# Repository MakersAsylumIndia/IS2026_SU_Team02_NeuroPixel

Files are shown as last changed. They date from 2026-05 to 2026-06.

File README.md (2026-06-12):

# IS2026 Summer - NeuroPixel: EMG-Controlled Accessible Gaming Console and Arcade Hub

**Description:**

NeuroPixel is an accessible EMG-controlled gaming console and arcade hub designed for individuals with physical disabilities and limited mobility. Instead of traditional controllers, the system uses EMG (Electromyography) sensors to detect voluntary muscle signals from areas such as the jaw, neck, shoulders, forehead, or facial muscles. These signals are processed by a microcontroller and converted into gameplay actions like jumping, moving, shooting, or selecting options.

The platform features five classic arcade-style games, including Google Chrome Dino, Flappy Bird, Pac-Man, Snake, and Space Invaders, all adapted for muscle-based interaction. NeuroPixel includes adaptive calibration, customizable sensitivity, audio feedback, and large visual indicators to ensure comfortable and accurate gameplay for users with varying levels of mobility and muscle strength.

Beyond entertainment, NeuroPixel also promotes cognitive engagement, reflex improvement, concentration, and neurological response development through interactive gameplay. Built using affordable and widely available components such as MyoWare EMG sensors and ESP32/Arduino microcontrollers, the system offers a low-cost and inclusive gaming solution. NeuroPixel bridges assistive technology, rehabilitation, and recreation, enabling users with disabilities to independently enjoy digital gaming experiences.

**Description of the contents od each folder:**

**CODE Folder**
Contains all software and programming files required for NeuroPixel. This includes EMG signal processing code, ESP32 firmware, calibration algorithms, game control mapping, Bluetooth/Wi-Fi communication scripts, and accessible game integration files for Chrome Dino, Flappy Bird, Pac-Man, Snake, and Space Invaders. It also includes testing scripts, debugging utilities, and libraries used for EMG signal filtering and command recognition.

**CAD Folder**
Contains all 3D design and mechanical files related to the physical structure of NeuroPixel. This includes enclosure designs, wearable sensor mounts, arcade console casing models, controller housing, mounting brackets, and assembly designs created using CAD software such as FreeCAD or Fusion 360. The folder may also include STL files for 3D printing and technical dimension drawings.

**Electronics Folder**
Contains circuit diagrams, wiring schematics, PCB layouts, component datasheets, and hardware integration details for the NeuroPixel system. This folder includes EMG sensor connections, ESP32/Arduino interfacing diagrams, power management circuits, OLED/display connections, battery systems, and calibration hardware documentation.

**Documentation Folder**
Contains project reports, research material, setup guides, user manuals, calibration instructions, accessibility documentation, testing reports, and presentation files explaining the working and objectives of NeuroPixel.

**Assets Folder**
Contains images, logos, UI graphics, sound effects, game icons, accessibility visuals, demo screenshots, and promotional material used in the NeuroPixel interface and presentations.

## License

Licenses

<a href="LICENSE.md">Open Source Licenses Facts</a>

#### Hardware
CERN Open Hardware License Version 2 - Strongly Reciprocal ([CERN-OHL-S-2.0](https://spdx.org/licenses/CERN-OHL-S-2.0.html)).

#### Software
MIT open source [license](http://opensource.org/licenses/MIT).

#### Documentation:
<br />This work is licensed under a <a rel="license" href="http://creativecommons.org/licenses/by/4.0/">Creative Commons Attribution 4.0 International License</a>.

---
## [OSHWA Certification](https://certification.oshwa.org/list.html)

[OSHW] IN000093 | Certified open source hardware | oshwa.org/cert

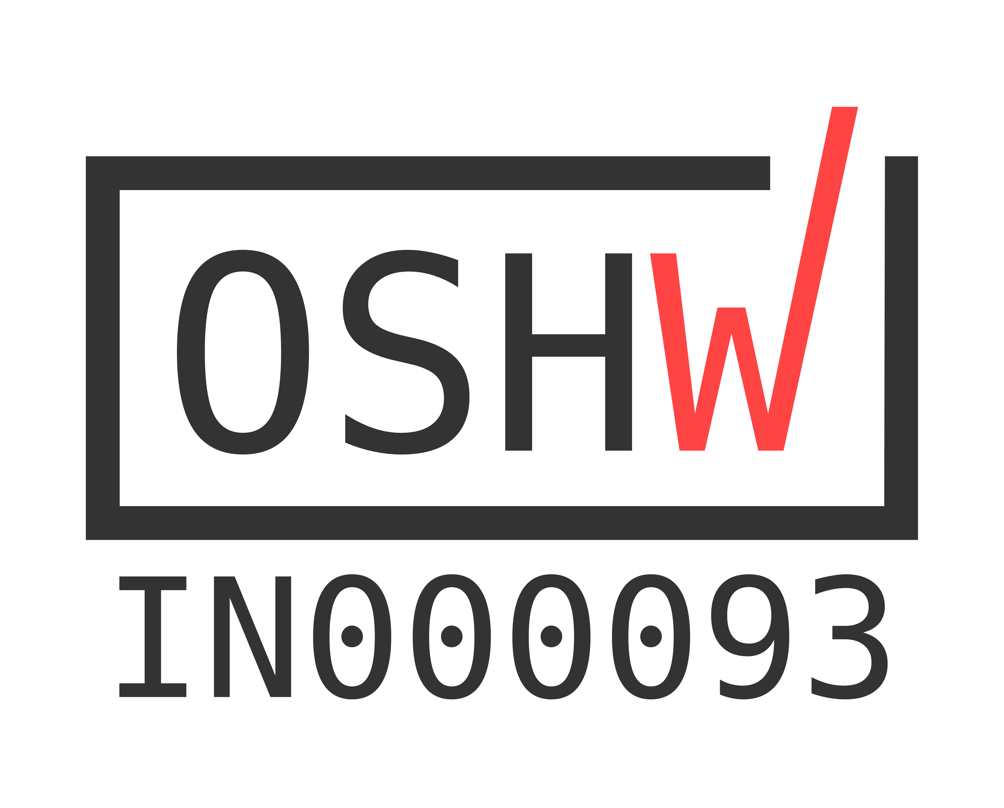
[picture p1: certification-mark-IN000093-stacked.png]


---

## 📬 Contact/Team

[@botadaranemi-arch] (https://github.com/botadaranemi-arch)

[@jatindixit3] (https://github.com/jatindixit3)

[@shreyasidaga] (https://github.com/shreyasidaga)

[@aryamanmehrotra1802-png] (https://github.com/aryamanmehrotra1802-png)

[@atharvkirloskar] (https://github.com/atharvkirloskar)

[Maker's Asylum] (https://github.com/MakersAsylumIndia)

> ---

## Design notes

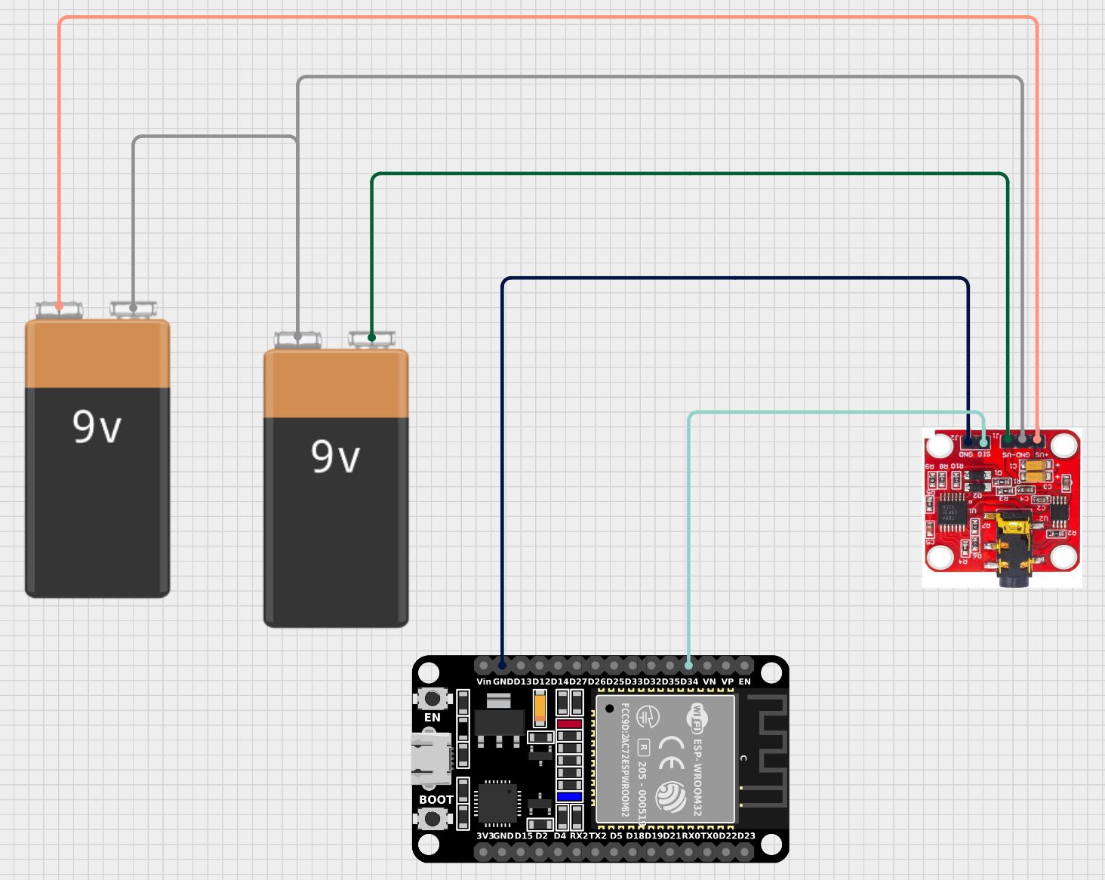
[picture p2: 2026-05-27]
Electronics/emg 1.jpeg

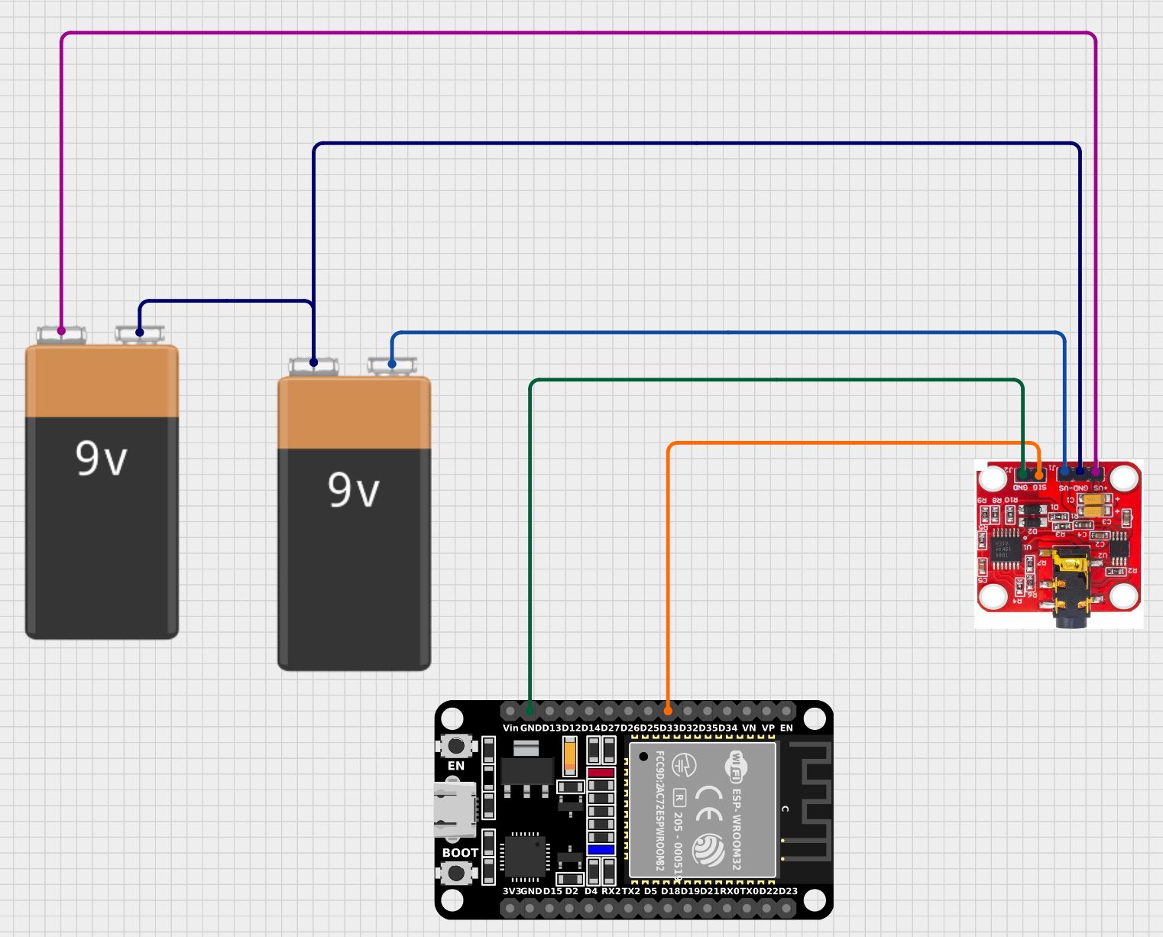
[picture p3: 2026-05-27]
Electronics/emg 4.jpeg

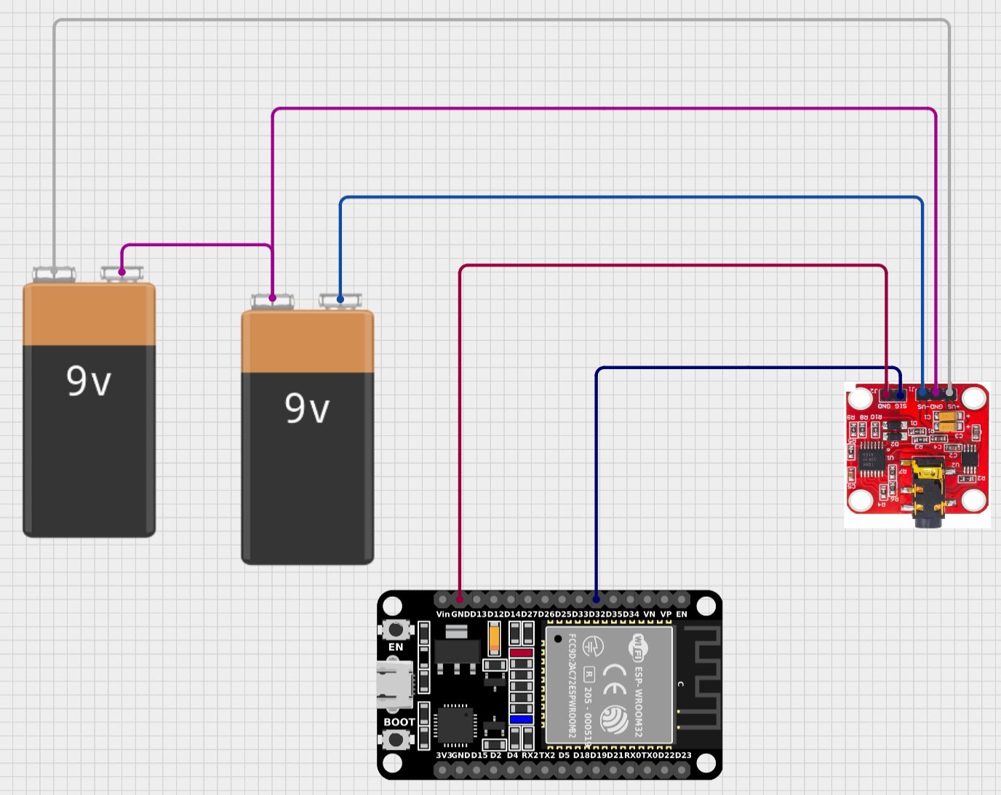
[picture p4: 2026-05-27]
Electronics/emg 3.jpeg

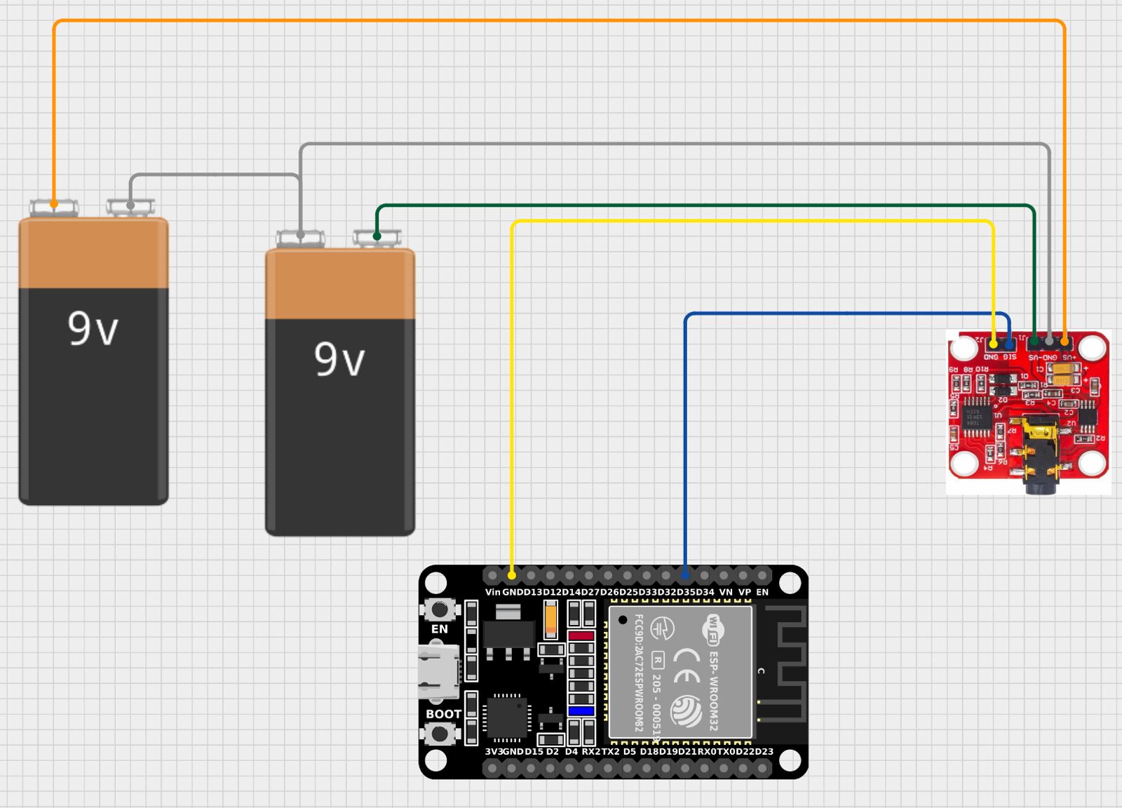
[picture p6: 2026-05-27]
Electronics/emg 2.jpeg

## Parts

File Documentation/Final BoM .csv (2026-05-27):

SR NO | PRODUCT NAME | QTY | TYPE | REFERENCE LINK | ADDITONAL DETAILS
1 | ESP32 Node MCU WiFi Bluetooth Development Module (30 Pin) - CP2102 MICRO | 3 | Electronics | https://www.flyrobo.in/esp32-node-mcu-wifi-bluetooth-development-module-30-pin?description=true | Main controller used to process EMG signals and run the project.
2 | EMG Muscle Sensor V3.0 with Cable and Electrodes | 5 | Electronics | https://robu.in/product/advancer-technologies-emg-muscle-sensor-v3-0-with-cable-and-electrodes/ | Detects electrical activity from muscles and converts it into readable signals.
3 | Bio Amp Muscle Band | 5 | Electronics | https://robu.in/product/muscle-bioamp-band-emg-band | Wearable band used to comfortably capture muscle movement signals from the body.
4 | WLY104050 3.7V 2500mAh 1S LiPo Battery (Wearable IoT) | 1 | Power | https://www.flyrobo.in/hw-battery-9v-for-arduino-rpi-robotics?description=true | Portable rechargeable battery used to power the wearable device.
5 | TP51000 Li-Ion Charging Module with Protection (Type-C) | 1 | Power | https://robu.in/product/tp5100-4-2v-8-4v-single-double-lithium-battery-charge-management-lion-battery-compatible-2a-charging-board | Charges the LiPo battery safely through a Type-C connector with protection features.
6 | Perf board double sided | 4 | Prototyping | https://robu.in/product/9-x-15-cm-universal-pcb-prototype-board-single-sided-2-54mm-hole-pitch?gad_source=1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 | Used to permanently solder and connect electronic components into a compact circuit.
7 | TP4056 1A Li-Ion Charging Board Micro USB with Protection | 1 | Power | https://robu.in/product/tp4056-1a-li-ion-battery-charging-board-micro-usb-with-current-protection-type-c-connector | Safely charges single-cell Li-ion/LiPo batteries using a Micro USB input.
8 | 20CM Dupont Wire Combo (M-M + M-F + F-F, 40pcs each = 120pcs) | 2 | Prototyping | https://robu.in/product/20-cm-40-pin-dupont-male-male-male-female-female-female-cable-combo/ | Used for temporary electrical connections between components during prototyping.
9 | 470 Ohm Resistor 1/4W (pack of 25) | 1 | Electronics | https://www.electropi.in/470-ohm-resistance?gad_source=1&gad_campaignid=23329895947 | Limits current flow to protect components and stabilize circuits.
10 | 75 Ohm Resistor 1/4W (pack of 25) | 1 | Electronics | https://www.electropi.in/75-ohm-resistance?gad_source=1&gad_campaignid=23329895947 | Used for signal conditioning, impedance matching, or current limiting in circuits.
11 | M3 Inserts | 1 | Mechanical | https://www.flyrobo.in/m2.5-x-5mm-brass-heat-set-threaded-round-insert-nut?tracking=ads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 | Provide strong threaded mounting points for screws in enclosures or 3D prints.
12 | Rca Composite Cable | 1 | Electronics | https://www.flyrobo.in/3.5mm-male-plug-3-rca-male-audio-video-cable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 | Transfers analog video or audio signals between devices.
13 | DC Jacks | 2 | Electronics | https://robu.in/product/audio-jack-pj306-3-5mm-female-connector | Used to connect external DC power supplies to electronic circuits.
14 | RCA to HDMI Upscaler | 1 | Electronics | https://robu.in/product/hdmi-to-av-adapter-hd-1080p-video-converter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 | Converts analog RCA video signals into digital HDMI output for modern displays.
15 | Powerbank | 1 | Power | https://amzn.in/d/0iMMmGR9 | Provides portable USB power supply for charging or running devices.

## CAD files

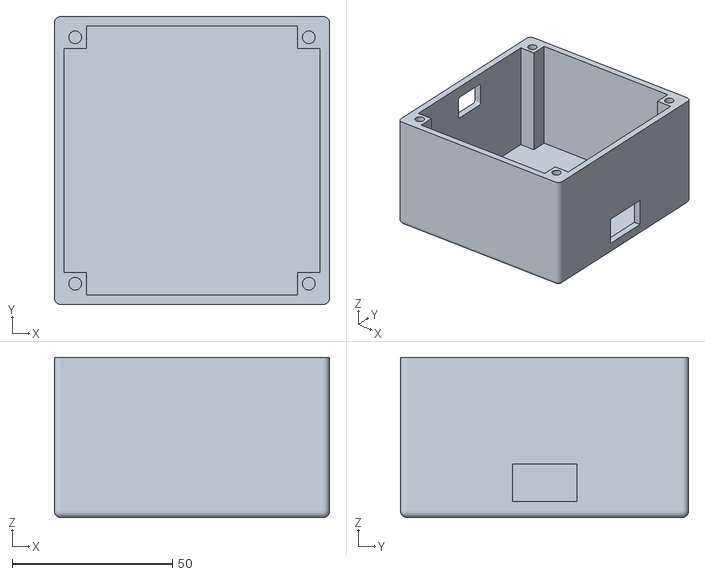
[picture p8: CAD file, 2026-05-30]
CAD/NeuroPixel Casing v2.1.stl
86.0 x 90.0 x 50.0

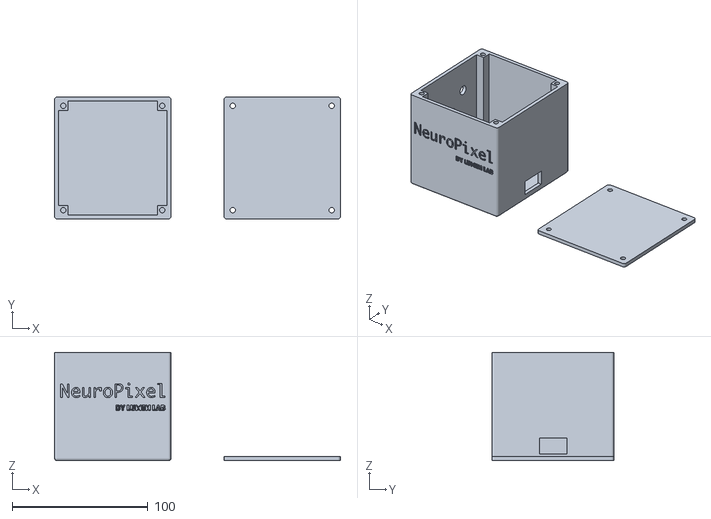
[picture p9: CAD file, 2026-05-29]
CAD/Final _ EMG Arcade Box and Top.stl
211.0 x 90.0 x 80.0

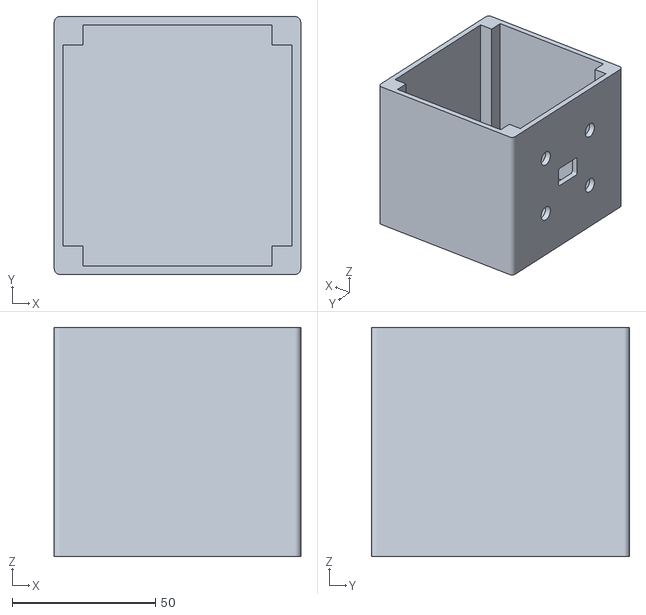
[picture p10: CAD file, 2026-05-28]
CAD/EMG Arcade Box.stl
86.0 x 90.0 x 80.0

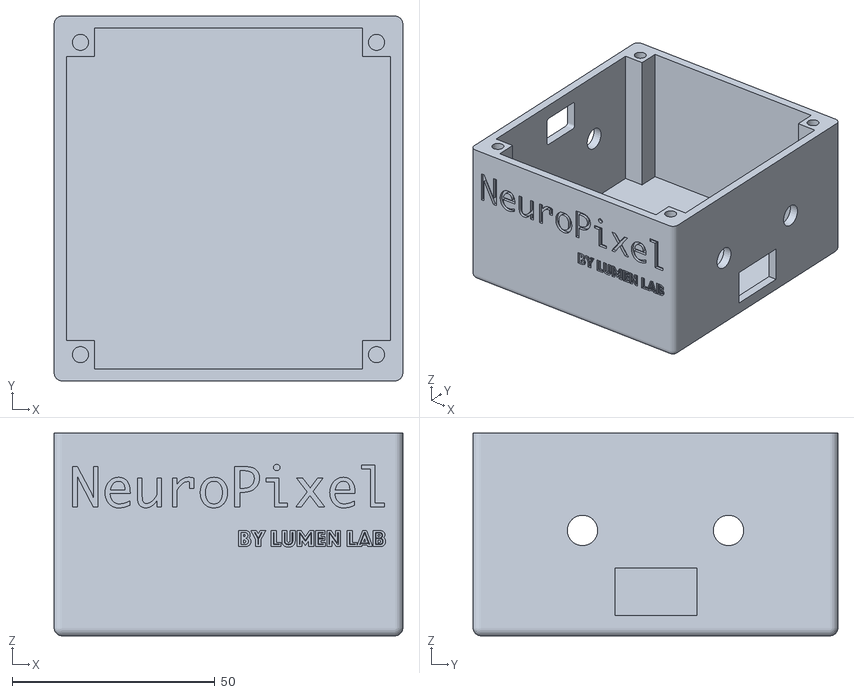
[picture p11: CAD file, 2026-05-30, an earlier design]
CAD/NeuroPixel Casing v2.stl
86.0 x 90.0 x 50.0

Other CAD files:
CAD/NeuroPixel Casing v1.stl

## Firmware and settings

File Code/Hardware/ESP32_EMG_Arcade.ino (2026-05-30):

#include <WiFi.h>
#include <WebServer.h>
#include <BleKeyboard.h>

const int emgPins[4] = {32, 33, 34, 35};
const char* emgLabels[4] = {"EMG 1 (LEFT)", "EMG 2 (RIGHT)", "EMG 3 (UP)", "EMG 4 (DOWN)"};

int thresholds[4] = {1500, 1500, 1500, 1500};

float alpha = 0.2;
float filteredValues[4] = {0, 0, 0, 0};

BleKeyboard bleKeyboard("NeuroPixel Arcade", "Lumen Lab", 100);
uint8_t arrowKeys[4] = {KEY_LEFT_ARROW, KEY_RIGHT_ARROW, KEY_UP_ARROW, KEY_DOWN_ARROW};
bool keyState[4] = {false, false, false, false};

const char* ssid = "NeuroPixel_Arcade";
const char* password = "password123";
WebServer server(80);

const char index_html[] PROGMEM = R"rawhtml(
<!DOCTYPE html>
<html lang="en">
<head>
<meta charset="UTF-8">
<meta name="viewport" content="width=device-width, initial-scale=1.0">
<title>NeuroPixel Retro Arcade</title>
<link href="https://fonts.googleapis.com/css2?family=Press+Start+2P&display=swap" rel="stylesheet">
<style>
:root{
  --bg:#070712;
  --surface:#0e0e22;
  --border:#1e1e40;
  --text:#e8e8ff;
  --muted:#4a4a80;
  --cyan:#00f5ff;
  --pink:#ff3cac;
  --yellow:#ffe000;
  --green:#39ff14;
  --orange:#ff6b00;
}
*{margin:0;padding:0;box-sizing:border-box;}
html,body{width:100%;height:100%;overflow:hidden;}
body{
  background:var(--bg);
  font-family:'Press Start 2P',monospace;
  color:var(--text);
  cursor:crosshair;
}

/* SCANLINES */
body::after{
  content:'';position:fixed;inset:0;pointer-events:none;z-index:9999;
  background:repeating-linear-gradient(0deg,transparent,transparent 3px,rgba(0,0,0,0.07) 3px,rgba(0,0,0,0.07) 4px);
}

/* ── MENU ── */
#menu{
  position:absolute;inset:0;
  display:flex;flex-direction:column;align-items:center;
  overflow-y:auto;overflow-x:hidden;
  padding:40px 20px 60px;
  transition:opacity 0.3s,transform 0.3s;
}
#menu.hidden{opacity:0;pointer-events:none;transform:scale(0.97);}

/* Starfield canvas behind menu */
#stars-canvas{position:fixed;inset:0;z-index:0;pointer-events:none;}

.menu-content{position:relative;z-index:1;width:100%;max-width:960px;display:flex;flex-direction:column;align-items:center;}

/* LOGO */
.logo-wrap{text-align:center;margin-bottom:10px;}
.logo-top{font-size:9px;letter-spacing:8px;color:var(--cyan);animation:blink 1.2s step-end infinite;}
.logo-main{
  font-size:clamp(22px,5vw,48px);
  line-height:1.25;
  margin:18px 0 8px;
  background:linear-gradient(135deg,var(--cyan),var(--pink),var(--yellow));
  -webkit-background-clip:text;-webkit-text-fill-color:transparent;background-clip:text;
  filter:drop-shadow(0 0 20px rgba(0,245,255,0.5));
  letter-spacing:3px;
}
.logo-sub{font-size:8px;letter-spacing:4px;color:var(--muted);margin-bottom:30px;}

@keyframes blink{0%,100%{opacity:1}50%{opacity:0}}

/* DIVIDER */
.neon-line{
  width:100%;max-width:600px;height:1px;margin:0 auto 40px;
  background:linear-gradient(90deg,transparent,var(--cyan),var(--pink),transparent);
  box-shadow:0 0 8px var(--cyan);
}

/* GAME GRID */
.game-grid{
  display:grid;
  grid-template-columns:repeat(auto-fit,minmax(250px,1fr));
  gap:18px;width:100%;
}

/* GAME CARD */
.gcard{
  background:var(--surface);
  border:1px solid var(--border);
  border-radius:2px;
  cursor:pointer;
  overflow:hidden;
  transition:transform 0.2s,border-color 0.2s,box-shadow 0.2s;
  position:relative;
}
.gcard:hover{
  transform:translateY(-5px);
  border-color:var(--c,var(--cyan));
  box-shadow:0 0 25px color-mix(in srgb, var(--c,var(--cyan)) 40%, transparent),0 10px 30px rgba(0,0,0,0.5);
}
.gcard-preview{
  height:120px;display:flex;align-items:center;justify-content:center;
  font-size:56px;
  position:relative;overflow:hidden;
}
.gcard-preview canvas{position:absolute;inset:0;opacity:0.35;}
.gcard-preview .icon{position:relative;z-index:1;filter:drop-shadow(0 0 12px var(--c,var(--cyan)));}

.gcard-body{padding:16px 18px 20px;}
.gcard-title{font-size:10px;color:var(--c,var(--cyan));margin-bottom:8px;
  text-shadow:0 0 10px var(--c,var(--cyan));}
.gcard-desc{font-size:7px;color:var(--muted);line-height:1.8;letter-spacing:0.5px;}
.gcard-cta{
  display:inline-block;margin-top:14px;
  font-size:7px;letter-spacing:1px;
  border:1px solid var(--c,var(--cyan));
  color:var(--c,var(--cyan));
  padding:6px 12px;
  transition:background 0.15s,color 0.15s;
}
.gcard:hover .gcard-cta{background:var(--c,var(--cyan));color:#000;}

.insert{margin-top:44px;font-size:8px;letter-spacing:3px;color:var(--muted);animation:blink 0.9s step-end infinite;}

.emg-nav-hint{
  margin-top:14px;
  font-size:7px;
  letter-spacing:2px;
  color:var(--cyan);
  opacity:0.7;
  text-align:center;
}

/* Selected card highlight */
.gcard.selected{
  transform:translateY(-5px);
  border-color:var(--c,var(--cyan));
  box-shadow:0 0 30px color-mix(in srgb, var(--c,var(--cyan)) 60%, transparent), 0 10px 30px rgba(0,0,0,0.5);
  outline:2px solid var(--c,var(--cyan));
  outline-offset:2px;
}

/* ── GAME SCREEN ── */
#gamescreen{
  position:absolute;inset:0;
  display:flex;flex-direction:column;
  opacity:0;pointer-events:none;
  transition:opacity 0.3s;
}
#gamescreen.active{opacity:1;pointer-events:all;}

.gsbar{
  height:46px;flex-shrink:0;
  background:#050510;
  border-bottom:1px solid var(--border);
  display:flex;align-items:center;justify-content:space-between;
  padding:0 14px;
  position:relative;z-index:10;
}
.gsbar-title{font-size:9px;letter-spacing:2px;color:var(--gc,var(--cyan));
  text-shadow:0 0 10px var(--gc,var(--cyan));}
.gsbar-score{font-size:8px;color:var(--muted);letter-spacing:2px;}

.back-btn{
  font-size:7px;letter-spacing:1px;
  background:transparent;border:1px solid var(--border);
  color:var(--muted);padding:6px 12px;cursor:pointer;
  transition:all 0.15s;font-family:'Press Start 2P',monospace;
}
.back-btn:hover{border-color:var(--pink);color:var(--pink);}

.game-wrap{
  flex:1;display:flex;align-items:center;justify-content:center;
  background:var(--gbg,#000);overflow:hidden;
  position:relative;
}
#game-canvas{display:block;image-rendering:pixelated;}

/* ── EMG INSTRUCTIONS OVERLAY ── */
#emg-overlay{
  position:absolute;inset:0;
  background:var(--bg);
  display:flex;flex-direction:column;align-items:center;justify-content:center;
  z-index:100;
  opacity:0;pointer-events:none;
  transition:opacity 0.3s;
  padding:30px 20px;
}
#emg-overlay.active{opacity:1;pointer-events:all;}

.emg-inner{
  width:100%;max-width:700px;
  display:flex;flex-direction:column;align-items:center;
  gap:28px;
}

.emg-game-label{
  font-size:7px;letter-spacing:3px;color:var(--muted);
  text-transform:uppercase;
}

.emg-title{
  font-size:clamp(13px,2.5vw,20px);
  letter-spacing:2px;
  color:var(--emg-color,var(--cyan));
  text-shadow:0 0 16px var(--emg-color,var(--cyan));
  text-align:center;
  line-height:1.5;
}

.emg-neon-line{
  width:100%;height:1px;
  background:linear-gradient(90deg,transparent,var(--emg-color,var(--cyan)),transparent);
  box-shadow:0 0 6px var(--emg-color,var(--cyan));
}

.emg-table{
  width:100%;
  display:grid;
  gap:0;
}
.emg-table.cols-4{ grid-template-columns:repeat(4,1fr); }
.emg-table.cols-3{ grid-template-columns:repeat(3,1fr); }
.emg-table.cols-2{ grid-template-columns:repeat(2,1fr); }
.emg-table.cols-1{ grid-template-columns:1fr; }

.emg-col{
  display:flex;flex-direction:column;
  padding:0 10px 0 0;
  border-right:1px solid var(--border);
}
.emg-col:last-child{ border-right:none; }

.emg-col-head{
  font-size:7px;letter-spacing:2px;
  color:var(--emg-color,var(--cyan));
  padding-bottom:10px;
  margin-bottom:10px;
  border-bottom:1px solid var(--border);
}

.emg-col-action{
  font-size:9px;
  color:var(--text);
  line-height:1.7;
  letter-spacing:0.5px;
}
.emg-col-action.unused{
  color:var(--muted);
  font-style:italic;
}

.emg-note{
  font-size:7px;color:var(--muted);letter-spacing:1px;line-height:2;
  text-align:center;
}

.emg-start-hint{
  font-size:8px;
  letter-spacing:2px;
  color:var(--emg-color,var(--cyan));
  opacity:0.85;
  text-align:center;
  animation:blink 1s step-end infinite;
}

.emg-hints-row{
  display:flex;
  gap:32px;
  justify-content:center;
  flex-wrap:wrap;
}

.emg-back-hint{
  font-size:8px;
  letter-spacing:2px;
  color:var(--muted);
  opacity:0.85;
  text-align:center;
  animation:blink 1s step-end infinite;
}

.emg-start-btn{
  font-family:'Press Start 2P',monospace;
  font-size:9px;letter-spacing:2px;
  background:transparent;
  border:1px solid var(--emg-color,var(--cyan));
  color:var(--emg-color,var(--cyan));
  padding:14px 32px;
  cursor:pointer;
  transition:background 0.15s,color 0.15s,box-shadow 0.15s;
  margin-top:4px;
}
.emg-start-btn:hover{
  background:var(--emg-color,var(--cyan));
  color:#000;
  box-shadow:0 0 20px var(--emg-color,var(--cyan));
}
</style>
</head>
<body>
<canvas id="stars-canvas"></canvas>

<!-- MENU -->
<div id="menu">
<div class="menu-content">
  <div class="logo-wrap">
    <div class="logo-top">▶ INSERT COIN ◀</div>
    <div class="logo-main">NEUROPIXEL<br>RETRO ARCADE</div>
    <div class="logo-sub">5 CLASSIC GAMES · BY LUMEN LAB</div>
  </div>
  <div class="neon-line"></div>
  <div class="game-grid" id="game-grid"></div>
  <div class="insert">▶ SELECT A GAME TO PLAY ◀</div>
  <div class="emg-nav-hint">EMG 1 ← NAVIGATE LEFT &nbsp;·&nbsp; EMG 2 → NAVIGATE RIGHT &nbsp;·&nbsp; EMG 3 SELECT</div>
</div>
</div>

<!-- GAME SCREEN -->
<div id="gamescreen">
  <div class="gsbar">
    <button class="back-btn" id="back-btn">◀ MENU</button>
    <div class="gsbar-title" id="gs-title">GAME</div>
    <div class="gsbar-score" id="gs-score">SCORE: 0</div>
  </div>
  <div class="game-wrap" id="game-wrap">
    <!-- EMG Instructions Overlay -->
    <div id="emg-overlay">
      <div class="emg-inner">
        <div class="emg-game-label" id="emg-game-label">EMG SENSOR MAPPING</div>
        <div class="emg-title" id="emg-title">LOADING...</div>
        <div class="emg-neon-line"></div>
        <div class="emg-table" id="emg-table"></div>
        <div class="emg-note" id="emg-note"></div>
        <div class="emg-hints-row">
          <div class="emg-start-hint">EMG 1 — START THIS GAME</div>
          <div class="emg-back-hint">EMG 2 — BACK TO HOME</div>
        </div>
        <button class="emg-start-btn" id="emg-start-btn">▶ START GAME</button>
      </div>
    </div>
    <canvas id="game-canvas"></canvas>
  </div>
</div>

<script>

// ═══════════════════════════════════════════════════════════
// STARFIELD
// ═══════════════════════════════════════════════════════════
(function(){
  const sc = document.getElementById('stars-canvas');
  const sx = sc.getContext('2d');
  let stars = [];
  function resizeSc(){sc.width=window.innerWidth;sc.height=window.innerHeight;}
  resizeSc();
  window.addEventListener('resize',resizeSc);
  for(let i=0;i<200;i++) stars.push({
    x:Math.random()*window.innerWidth,y:Math.random()*window.innerHeight,
    r:Math.random()*1.2+0.2,spd:Math.random()*0.3+0.05,
    op:Math.random()
  });
  function animStars(){
    sx.clearRect(0,0,sc.width,sc.height);
    for(const st of stars){
      st.y+=st.spd; if(st.y>sc.height){st.y=0;st.x=Math.random()*sc.width;}
      st.op+=0.02*(Math.random()-0.5); st.op=Math.max(0.1,Math.min(1,st.op));
      sx.fillStyle=`rgba(180,180,255,${st.op})`;
      sx.beginPath();sx.arc(st.x,st.y,st.r,0,Math.PI*2);sx.fill();
    }
    requestAnimationFrame(animStars);
  }
  animStars();
})();

// ═══════════════════════════════════════════════════════════
// GAME REGISTRY
// ═══════════════════════════════════════════════════════════
const GAME_META = [
  {id:'snake',    title:'SNAKE',          desc:'Eat apples · grow longer', icon:'🐍', color:'#39ff14', bg:'#061206'},
  {id:'flappy',   title:'FLAPPY BIRD',    desc:'Tap to flap · dodge the pipes',          icon:'🐦', color:'#ffe000', bg:'#1a3a5c'},
  {id:'dino',     title:'CHROME DINO',    desc:'Jump cacti · duck pterodactyls',          icon:'🦕', color:'#aaaaaa', bg:'#f0f0f0'},
  {id:'invaders', title:'SPACE INVADERS', desc:'Shoot aliens · defend Earth',             icon:'👾', color:'#00f5ff', bg:'#000510'},
  {id:'pacman',   title:'PAC-MAN',        desc:'Eat dots · dodge ghosts · hunt them',    icon:'🟡', color:'#ffe000', bg:'#000020'},
];

// Build cards
const grid = document.getElementById('game-grid');
GAME_META.forEach(g=>{
  const card = document.createElement('div');
  card.className='gcard';
  card.style.setProperty('--c',g.color);
  card.innerHTML=`
    <div class="gcard-preview" style="background:${g.bg}">
      <span class="icon">${g.icon}</span>
    </div>
    <div class="gcard-body">
      <div class="gcard-title">${g.title}</div>
      <div class="gcard-desc">${g.desc}</div>
      <div class="gcard-cta">▶ PLAY</div>
    </div>`;
  card.addEventListener('click',()=>launchGame(g.id));
  grid.appendChild(card);
});

// ═══════════════════════════════════════════════════════════
// MENU KEYBOARD / EMG NAVIGATION
// ═══════════════════════════════════════════════════════════
let selectedIdx = 0; // Snake starts selected

function getCards(){ return Array.from(document.querySelectorAll('.gcard')); }

function setSelected(idx){
  const cards = getCards();
  cards.forEach((c,i)=> c.classList.toggle('selected', i===idx));
  // Scroll card into view if needed
  cards[idx].scrollIntoView({behavior:'smooth', block:'nearest', inline:'center'});
}

// Select Snake (index 0) on load
window.addEventListener('DOMContentLoaded', ()=> setSelected(0));
// Also fire immediately in case DOMContentLoaded already passed
setSelected(0);

document.addEventListener('keydown', e=>{
  // Only act when menu is visible
  if(document.getElementById('menu').classList.contains('hidden')) return;
  const cards = getCards();
  if(e.key === 'ArrowLeft'){
    e.preventDefault();
    selectedIdx = (selectedIdx - 1 + cards.length) % cards.length;
    setSelected(selectedIdx);
  } else if(e.key === 'ArrowRight'){
    e.preventDefault();
    selectedIdx = (selectedIdx + 1) % cards.length;
    setSelected(selectedIdx);
  } else if(e.key === 'Enter' || e.key === ' '){
    e.preventDefault();
    e.stopImmediatePropagation(); // prevent the EMG overlay's keydown listener from also firing on this same Enter press
    launchGame(GAME_META[selectedIdx].id);
  }
});

// ═══════════════════════════════════════════════════════════
// NAVIGATION
// ═══════════════════════════════════════════════════════════
let currentGame = null;
let currentGameId = null;

function restartWithOverlay(){
  if(!currentGameId) return;
  const meta = GAME_META.find(g=>g.id===currentGameId);
  const canvas = document.getElementById('game-canvas');
  if(currentGame && currentGame.destroy){ currentGame.destroy(); currentGame=null; }
  showEMGOverlay(currentGameId, meta.color, ()=>{
    currentGame = startGame(currentGameId, canvas);
  });
}

function launchGame(id){
  currentGameId = id;
  const meta = GAME_META.find(g=>g.id===id);
  document.getElementById('menu').classList.add('hidden');
  const gs = document.getElementById('gamescreen');
  gs.classList.add('active');
  gs.style.setProperty('--gc', meta.color);
  document.getElementById('gs-title').textContent = meta.title;
  document.getElementById('gs-score').textContent = 'SCORE: 0';
  document.getElementById('game-wrap').style.background = meta.bg;

  const canvas = document.getElementById('game-canvas');
  if(currentGame && currentGame.destroy) currentGame.destroy();
  currentGame = null;

  // Show EMG instructions first; start game when player clicks START
  showEMGOverlay(id, meta.color, ()=>{
    currentGame = startGame(id, canvas);
  });
}

function returnToMenu(){
  document.getElementById('menu').classList.remove('hidden');
  document.getElementById('gamescreen').classList.remove('active');
  document.getElementById('emg-overlay').classList.remove('active');
  if(currentGame && currentGame.destroy){ currentGame.destroy(); currentGame=null; }
  setSelected(selectedIdx);
}

document.getElementById('back-btn').addEventListener('click', returnToMenu);
document.addEventListener('keydown', e=>{
  if(e.key==='Escape') returnToMenu();
  const overlay = document.getElementById('emg-overlay');
  if(overlay.classList.contains('active')){
    // Enter starts the game
    if(e.key==='Enter'){
      e.preventDefault();
      document.getElementById('emg-start-btn').click();
    }
    // ArrowLeft goes back to home
    if(e.key==='ArrowLeft'){
      e.preventDefault();
      returnToMenu();
    }
  }
});

function updateScore(s){
  document.getElementById('gs-score').textContent='SCORE: '+s;
}


// ═══════════════════════════════════════════════════════════
// EMG INSTRUCTIONS
// ═══════════════════════════════════════════════════════════
const EMG_CONFIG = {
  snake: {
    title: 'Using Four EMGs: Snake',
    cols: 4,
    sensors: [
      { head:'EMG 1', action:'Move left ←' },
      { head:'EMG 2', action:'Move right →' },
      { head:'EMG 3', action:'Move up ↑' },
      { head:'EMG 4', action:'Move down ↓' },
    ],
    note: 'Contract the corresponding muscle to move the snake in that direction.',
  },
  flappy: {
    title: 'Using One EMG: Flappy Bird',
    cols: 1,
    sensors: [
      { head:'EMG 1', action:'Fly / Jump up' },
    ],
    note: 'Contract your muscle to flap and keep the bird airborne.',
  },
  dino: {
    title: 'Using Two EMGs: Chrome Dino',
    cols: 2,
    sensors: [
      { head:'EMG 1', action:'Jump up' },
      { head:'EMG 2', action:'Duck down' },
    ],
    note: 'Use two different muscles to jump over cacti and duck under pterodactyls.',
  },
  invaders: {
    title: 'Using Three EMGs: Space Invaders',
    cols: 4,
    sensors: [
      { head:'EMG 1', action:'Move left ←' },
      { head:'EMG 2', action:'Move right →' },
      { head:'EMG 3', action:'Fire' },
      { head:'EMG 4', action:'Not used', unused:true },
    ],
    note: 'A fourth EMG sensor is optional — only three are required to play.',
  },
  pacman: {
    title: 'Using Four EMGs: Pac-Man',
    cols: 4,
    sensors: [
      { head:'EMG 1', action:'Move left ←' },
      { head:'EMG 2', action:'Move right →' },
      { head:'EMG 3', action:'Move up ↑' },
      { head:'EMG 4', action:'Move down ↓' },
    ],
    note: 'Contract the corresponding muscle to steer Pac-Man through the maze.',
  },
};

function showEMGOverlay(gameId, accentColor, onStart){
  const cfg = EMG_CONFIG[gameId];
  const overlay = document.getElementById('emg-overlay');

  // Set accent colour via CSS variable
  overlay.style.setProperty('--emg-color', accentColor);

  document.getElementById('emg-game-label').textContent = 'EMG SENSOR MAPPING';
  document.getElementById('emg-title').textContent = cfg.title.toUpperCase();

  // Build table
  const table = document.getElementById('emg-table');
  table.className = `emg-table cols-${cfg.cols}`;
  table.innerHTML = cfg.sensors.map(s=>`
    <div class="emg-col">
      <div class="emg-col-head">${s.head}</div>
      <div class="emg-col-action${s.unused?' unused':''}">${s.action}</div>
    </div>
  `).join('');

  document.getElementById('emg-note').textContent = cfg.note;

  overlay.classList.add('active');

  const btn = document.getElementById('emg-start-btn');
  // Clone to drop old listeners
  const fresh = btn.cloneNode(true);
  btn.parentNode.replaceChild(fresh, btn);
  fresh.addEventListener('click', ()=>{
    overlay.classList.remove('active');
    onStart();
  });
}


// ═══════════════════════════════════════════════════════════
// GAME DISPATCHER
// ═══════════════════════════════════════════════════════════
function startGame(id, canvas){
  switch(id){
    case 'snake':    return gameSnake(canvas);
    case 'flappy':   return gameFlappy(canvas);
    case 'dino':     return gameDino(canvas);
    case 'invaders': return gameInvaders(canvas);
    case 'pacman':   return gamePacman(canvas);
  }
}
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
void loop() {
  server.handleClient();

  if (bleKeyboard.isConnected()) {
    for (int i = 0; i < 4; i++) {
      int rawValue = analogRead(emgPins[i]);
      filteredValues[i] = (alpha * rawValue) + ((1.0 - alpha) * filteredValues[i]);
      if (filteredValues[i] > thresholds[i]) {
        if (!keyState[i]) {
          bleKeyboard.press(arrowKeys[i]);
          keyState[i] = true;
        }
      } else {
        if (keyState[i]) {
          bleKeyboard.release(arrowKeys[i]);
          keyState[i] = false;
        }
      }
    }
  }

  Serial.printf("%-11.0f| %-11.0f| %-11.0f| %.0f\n",
                filteredValues[0], filteredValues[1], filteredValues[2], filteredValues[3]);

  delay(20);
}

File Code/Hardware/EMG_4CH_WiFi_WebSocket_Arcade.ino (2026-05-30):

#include <WiFi.h>
#include <WebSocketsServer.h>

#define EMG1_PIN  34    // LEFT
#define EMG2_PIN  35    // RIGHT
#define EMG3_PIN  32    // UP
#define EMG4_PIN  33    // DOWN

#define THRESHOLD_1  1800
#define THRESHOLD_2  1800
#define THRESHOLD_3  1800
#define THRESHOLD_4  1800

#define ALPHA  0.15f

#define AP_SSID  "NeuroPixel"
#define AP_PASS  "neuropixel123"

#define WS_SEND_MS      20
#define SERIAL_MS      100
#define HEADER_EVERY   30

WebSocketsServer webSocket(81);

const uint8_t  EMG_PINS[4]    = { EMG1_PIN,  EMG2_PIN,  EMG3_PIN,  EMG4_PIN  };
const int      THRESHOLDS[4]  = { THRESHOLD_1, THRESHOLD_2, THRESHOLD_3, THRESHOLD_4 };
const char*    KEY_NAMES[4]   = { "LEFT", "RIGHT", "UP", "DOWN" };
const char*    COL_HEADS[4]   = { "EMG1(L)", "EMG2(R)", "EMG3(U)", "EMG4(D)" };

float   filtered[4]   = { 0, 0, 0, 0 };
bool    active[4]     = { false, false, false, false };

unsigned long lastWs     = 0;
unsigned long lastSerial = 0;
int           lineCount  = 0;

void setup() {
  Serial.begin(115200);
  delay(200);
  analogReadResolution(12);
  analogSetAttenuation(ADC_11db);

  for (int i = 0; i < 4; i++) {
    filtered[i] = (float)analogRead(EMG_PINS[i]);
  }

  WiFi.softAP(AP_SSID, AP_PASS);
  Serial.print("[WiFi] AP started  SSID: "); Serial.println(AP_SSID);
  Serial.print("[WiFi] IP: "); Serial.println(WiFi.softAPIP());

  webSocket.begin();
  webSocket.onEvent(wsEvent);
  Serial.println("[WS] WebSocket server on port 81");
  Serial.println();
  printHeader();
}

void loop() {
  webSocket.loop();
  unsigned long now = millis();

  for (int i = 0; i < 4; i++) {
    int raw    = analogRead(EMG_PINS[i]);
    filtered[i] = ALPHA * (float)raw + (1.0f - ALPHA) * filtered[i];
    active[i]   = ((int)filtered[i] >= THRESHOLDS[i]);
  }

  if (now - lastWs >= WS_SEND_MS) {
    broadcastState();
    lastWs = now;
  }

  if (now - lastSerial >= SERIAL_MS) {
    printColumns();
    lastSerial = now;
  }
}

void printHeader() {
  Serial.println("EMG1(L)    EMG2(R)    EMG3(U)    EMG4(D)");
  Serial.println("--------   --------   --------   --------");
  lineCount = 0;
}

void printColumns() {
  if (lineCount >= HEADER_EVERY) {
    Serial.println();
    printHeader();
  }
  for (int i = 0; i < 4; i++) {
    int val = (int)filtered[i];
    char buf[12];
    if (active[i]) snprintf(buf, sizeof(buf), "[%4d]     ", val);
    else           snprintf(buf, sizeof(buf), " %4d      ", val);
    Serial.print(buf);
  }
  Serial.println();
  lineCount++;
}

void broadcastState() {
  String msg = "{\"keys\":[";
  bool first = true;
  for (int i = 0; i < 4; i++) {
    if (active[i]) {
      if (!first) msg += ',';
      msg += '"'; msg += KEY_NAMES[i]; msg += '"';
      first = false;
    }
  }
  msg += "],\"vals\":[";
  for (int i = 0; i < 4; i++) {
    msg += (int)filtered[i];
    if (i < 3) msg += ',';
  }
  msg += "]}";
  webSocket.broadcastTXT(msg);
}

void wsEvent(uint8_t num, WStype_t type, uint8_t* payload, size_t length) {
  switch (type) {
    case WStype_CONNECTED:
      Serial.print("[WS] Client #"); Serial.print(num);
      Serial.print(" connected from ");
      Serial.println(webSocket.remoteIP(num).toString());
      broadcastState();
      break;
    case WStype_DISCONNECTED:
      Serial.print("[WS] Client #"); Serial.print(num);
      Serial.println(" disconnected");
      break;
    default: break;
  }
}

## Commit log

2026-05-26 day 1 media
    These images document the first day of the NeuroPixel project, focused on building the foundation of the EMG-controlled arcade system. During this phase, the five arcade games were developed and test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
2026-05-26 day 2 media
    These images show the second day of the NeuroPixel project, where all five arcade games were successfully integrated into a single unified webpage. The system was tested thoroughly to ensure smooth navigation, stable graphics performance, accurate outputs, and responsive controls using keyboard inputs as temporary replacements for EMG-based interaction. Serial monitor testing was also carried out to verify system behavior and prepare the platform for future EMG sensor integration.
2026-05-27 Datasheet
    The ESP32 datasheet contains specifications about its processor, Wi-Fi/Bluetooth features, GPIO pins, memory, and communication protocols used in embedded systems.
    The OLED display datasheet explains display resolution, power requirements, and I2C/SPI interfacing methods for showing text and graphics.
    The EMG sensor datasheet describes how muscle electrical signals are detected, amplified, and converted into readable outputs.
    These datasheets also provide pin diagrams, electrical characteristics, and operating conditions for proper circuit design.
2026-05-27 Circuit Designs and URLs
    The circuit design consists of EMG sensors, two 9V batteries, and an ESP32.
    The EMG sensors detect muscle signals and send the data to the ESP32 for processing.
    The two 9V batteries provide power to the entire system for efficient operation.
2026-05-27 Circuit URLs
    The circuit design uses EMG sensors, two 9V batteries, and an ESP32 connected through proper circuit layouts and wiring.
    The design ensures accurate detection of muscle signals and efficient data processing by the ESP32.
    Proper connections and power supply management improve the reliability and performance of the circuit system.
2026-05-27 Final BoM
2026-05-27 Day 3 - Videos
    The project development began with the use of a breadboard for initial prototyping and hardware testing. During the early testing phase, five EMG sensor inputs were evaluated, out of which four sensors were found to be functioning properly while one sensor did not respond as expected. This stage mainly focused on validating signal acquisition, stability, and responsiveness of the EMG setup before integrating it with the software system. On the software side, the codebase and web interface were developed to support multiple interactive game environments, and most of the debugging work has already been completed to ensure smoother performance and better system reliability.
    At t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
2026-05-27 Create Test code for indivisual EMG sensor
    Test code for EMG sensor
2026-05-27 Create 4_EMG_TEST
    Test code for all 4 EMG sensors together
2026-05-27 Day 3 - Videos
    At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
2026-05-27 Delete Documentation/Final BoM .numbers
    The files is in .numbers format replacing it with a .csv file.
2026-05-27 Final BoM
    This Bill of Materials (BOM) consists of electronic components and accessories required for developing a wearable IoT-based EMG muscle sensing system. The main controller used is the ESP32 Node MCU, 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
    [Final BoM .csv]
2026-05-27 Day 3 - Photos
    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
2026-05-28 Add files via upload
    Dino game tesing with emg sensor
2026-05-28 Add files via upload
    Dino game testing with emg sensor
2026-05-28 Day 4 videos
    Today, all four EMG sensors were tested individually and confirmed to be functioning properly. We also worked on the CAD design of the enclosure box that will house all the system components. The enclosure model was designed using Sun Board, and the design is now almost finalized.
    In addition, we successfully controlled the Chrome Dino game using a single EMG sensor. The software and website interface were fully finalized, with the controls working through arrow key inputs. During testing, the ESP32 board was replaced with the XIAO ESP32-S3 board, which resulted in improved performance and better overall system stability.
    The EMG sensor was able to capture strong and relia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
2026-05-28 Day 4 - CAD
    CAD Model for Casing of EMG Arcade.
    [EMG Arcade Box.stl]
2026-05-28 Day 4 - Photos
    The EMG sensor was able to capture strong and reliabl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
2026-05-28 Day 4 - Photos
    In addition, we successfully controlled the Chrome Dino game using a single EMG sensor. The software and website interface were fully finalized, with the controls working through arrow key inputs. During testing, the ESP32 board was replaced with the XIAO S3 board, which resulted in improved performance and better overall system stability.
    The EMG sensor was able to capture strong and reliable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
2026-05-28 Day 4 - Photos
    The EMG sensor was able to capture strong and rel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
2026-05-28 Day 4 - Photos
    The EMG sensor was able to capture strong and reliable sign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
2026-05-29 Day 4 - Videos
    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
2026-05-29 Day 4 - Videos
    The EMG sensor was able to capture strong and reliab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
2026-05-29 esp32- s3 datasheet
2026-05-29 esp32- s3 pinout
2026-05-29 Day 5 - CAD Casing
    Final CAD Design made for the casing of NeuroPixel that will contain 4 EMG Sensors, ESP32, and two 9V batteries. Model given for 3D printing and top of the casing laser cut.
    [Final _ EMG Arcade Box and Top.stl]
2026-05-30 day 5 media
    On Day 5, significant progress was made in integrating and testing the NeuroPixel EMG gaming system. Two of the four EMG sensors were functioning reliably and producing stable outputs. The team switc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
    Gameplay testing was conducted using Google Chrome Dino and Flappy Bird. The EMG-based controls successfully triggered upward and downward movements, demonstrating that muscle signals could be transl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
2026-05-30 day 5 videos
    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
2026-05-30 Day 6 - Final CAD Casing
    Final CAD casing that was submitted a day before was printed within 2 hours and 45 minutes. Alongside a new smaller casing was designed with the only change being the height of the casing reduced by 30mm and the holes for the EMG jack of two sensors that were previously designed with all 4 on one side were modified to two on the front and two on the back side of the casing. The text 'By Lumen Lab' didn't print well because of the nozzle size of the Bambu Labs P1S Combo 3D Printer. The text size was increase in the V2.1 along with change in the font type.
    [NeuroPixel Casing v1.stl, NeuroPixel Casing v2.1.stl, NeuroPixel Casing v2.stl]
2026-05-30 Delete esp32- s3 pinout.jpg
    Upload in the wrong place.
2026-05-30 Pinout for XIOA ESP-32 S3
    The XIOA S3 Board was used since the ADC Pins of the ESP32 led to a lot of noise. The ADC pins of the XIOS S3 were surmised to be less noisy and hence the board was used. However, further along the XIOA Board was not compatible with the system and hence the ESP32 was utilised finally.
2026-05-30 day 6 media
    our CAD casing to hold our components
2026-05-31 day 6 media
    our final prototype
2026-05-31 day 6 video
    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
